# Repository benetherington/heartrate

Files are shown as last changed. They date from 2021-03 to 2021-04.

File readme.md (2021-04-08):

# benetherington/heartrate
A quick Arduino sketch using a Polar heartrate receiver to display individual
heartbeats, averaged heartrate, and a heartrate histogram.

## Dependencies
contrem/arduino-timer

## Hardware

* [Adafruit FeatherWing OLED - 128x64 OLED Add-on For Feather - STEMMA QT / Qwiic](https://www.adafruit.com/product/4650)

* [Heart Rate Educational Starter Pack with Polar Wireless Sensors](https://www.adafruit.com/product/1077)

* [Adafruit Feather M0 WiFi - ATSAMD21 + ATWINC1500](https://www.adafruit.com/product/3010) (Though you'd be hard
  pressed to find a Feather that wouldn't work!)

* [3.7v Li-Ion battery](https://www.adafruit.com/product/328) The enclosure is sized for Adafruit's biggest, linked
  here. It's 2500mAh.

## 3D Printed Enclosure
In the CAD folder, you'll find the original FreeCAD files, STLs of the four
parts, and two pre-sliced Gcode files for the Prusa Mk3. You'll also need velcro
cable straps, and an M3 flat-head screw. I used a 10mm long screw to take
advantage of the extra bite at the back of the hole which is printed as an
overhang in this orientation, but a shorter one would work as well. You don't
need much holding power here.

There are a few things to note about these files:
* The bottomcase has mounting posts spaced for the M0 WiFi. They're wider than
  the Feather standard calls for. If you use another, you'll have to modify the
  file. In the left sidebar, navigate to Enclosure > bottomcase > posts002 >
  posts001, and change constraint 4.
* If you don't want to use a screw for the battery door, consider adding tabs to
  the top of the door and the top of the door frame. The tabs holding the
  topcase and bottomcase together are a good example of how this might look.
* This design does not feature easy access to the USB port. I figured protection
  against sweat droplets was a priority. Instead, I spec'd Adafruit's biggest
  JST battery and added sleep capabilities to the Arduino code.

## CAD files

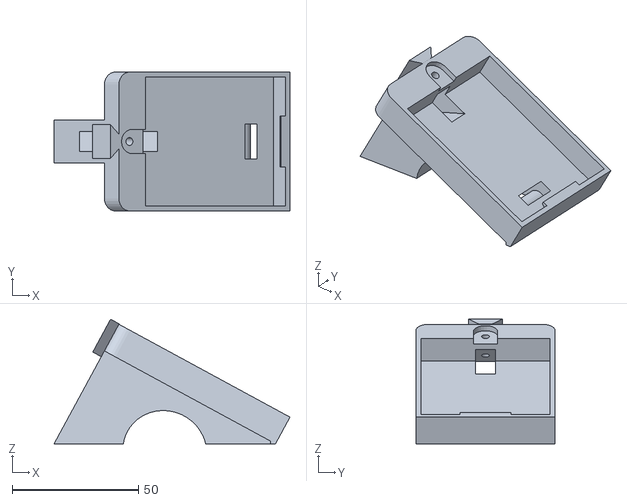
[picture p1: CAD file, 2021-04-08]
CAD/battery_and_mount.stl
93.3 x 55.0 x 49.3

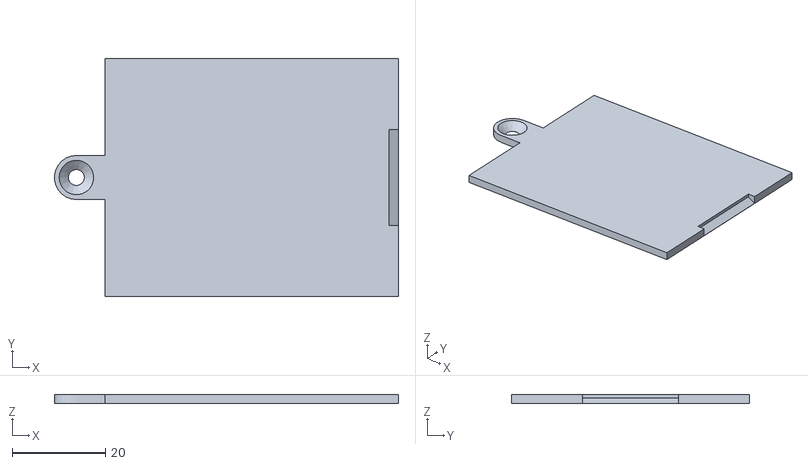
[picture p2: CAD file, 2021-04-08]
CAD/battery_door.stl
73.6 x 50.8 x 2.00

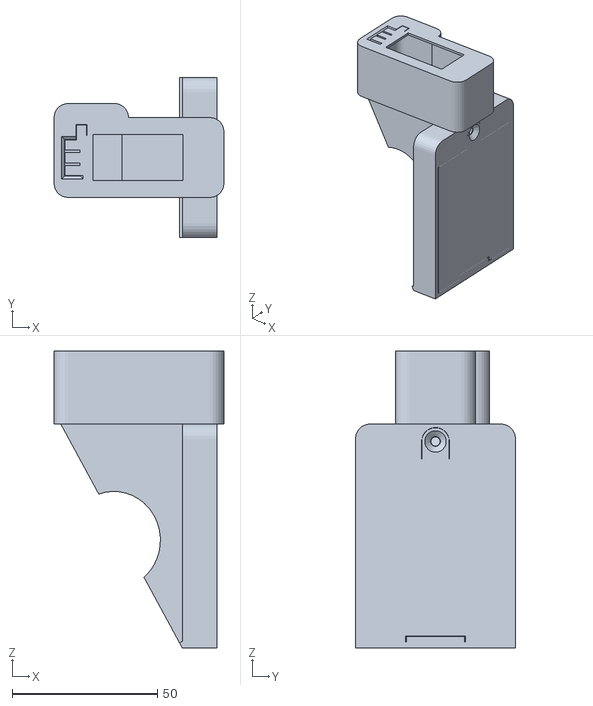
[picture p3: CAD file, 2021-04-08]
CAD/enclosure.stl
58.4 x 55.0 x 102.1

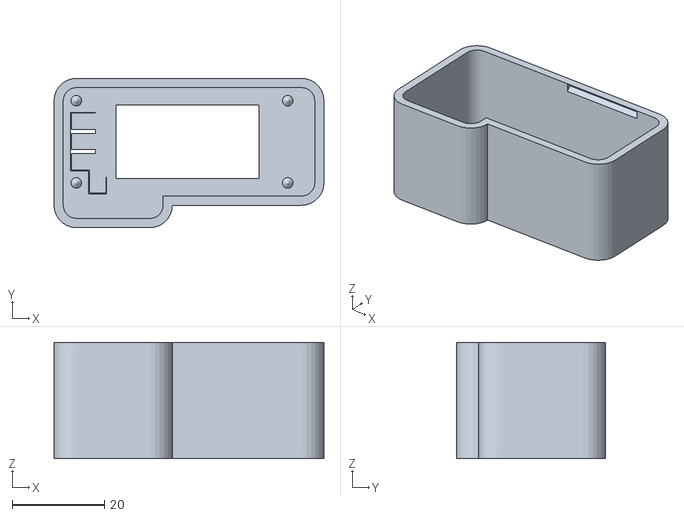
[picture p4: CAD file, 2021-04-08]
CAD/topcase.stl
58.4 x 32.3 x 25.1

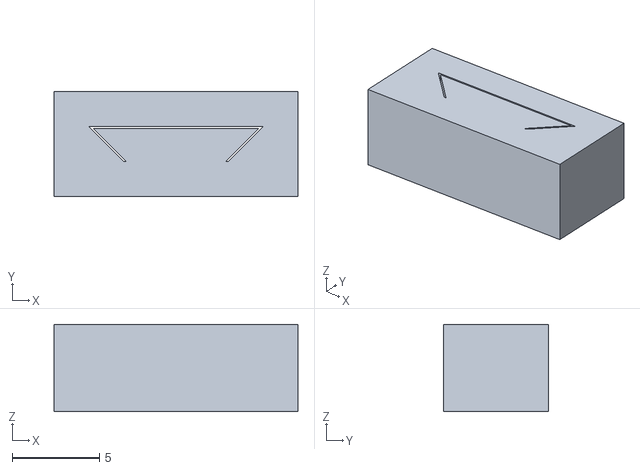
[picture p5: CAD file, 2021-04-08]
CAD/dovetail_test.stl
14.0 x 6.00 x 5.00

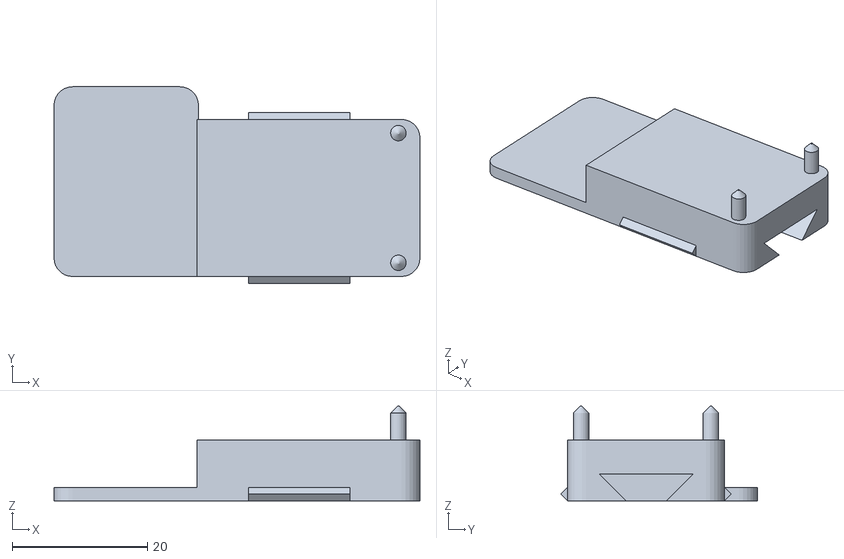
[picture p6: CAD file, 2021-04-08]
CAD/bottomcase.stl
54.2 x 29.1 x 14.0

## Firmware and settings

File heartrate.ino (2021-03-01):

#include <SPI.h>
#include <Wire.h>
#include <Adafruit_GFX.h>
#include <Adafruit_SH110X.h>
#include "arduino-timer.h"
#include "heartrate.h"

// IO
#define HR_RX     12
#define LED       13
#define BUTTON_A  9
#define BUTTON_B  6
#define BUTTON_C  5
Adafruit_SH110X display = Adafruit_SH110X(64, 128, &Wire);

// TIMERS
Timer<2>               timer;             // flash_heart, update_display.
Timer<2, millis, int>  led_timer;         // blink_led, led_off. Takes delay.
Timer<1, millis, bool> heart_pulse_timer; // display_heart_interior. Takes filled.

// CONFIGURABLE
#define FASTBLINK         100  // Blinkenlights for fun and debugging
#define SLOWBLINK         1000 //
#define HR_SAMPLE_RATE    2500 // Milliseconds to wait before displaying a new averaged HR
#define DISP_SPARK_HR_MIN 75   // Sparkline Y min in BPM
#define DISP_SPARK_HR_MAX 180  // Sparkline Y max in BPM

// GUI ARRANGEMENT
#define DISP_HEART_X 95 // Pulsing heart
#define DISP_HEART_Y 0  //
#define DISP_RATE_X  94 // Heartrate numerical display
#define DISP_RATE_Y  40 //
#define DISP_GRAPH_X 0  // Sparkline
#define DISP_GRAPH_Y 0  //
#define DISP_GRAPH_W 93 //
#define DISP_GRAPH_H 64 //


// GLOBALS
byte oldSample, sample;
bool newHeartbeat = false;
unsigned long heartrateSinceMillis = millis();
int heartbeatsSince = 0;



/* -------------- *\
|                  |
|  SETUP AND LOOP  |
|                  |
\* -------------- */

void setup() {
  // Change the true/false below to hotswap to button A as an alternate heartrate input.
  // This causes some odd behaviors due to the swapped polarity, but it's good enough for debugging.
  int debug_input;
  if (false) {
    debug_input = BUTTON_A;
  } else {
    debug_input = HR_RX;
  }

  // Set up pins, display, timers, callbacks
  Serial.begin(9600);
  Serial.println("INIT PINS");
  pinMode (HR_RX, INPUT);
  pinMode(LED, OUTPUT);
  pinMode(BUTTON_A, INPUT_PULLUP);
  pinMode(BUTTON_B, INPUT_PULLUP);
  pinMode(BUTTON_C, INPUT_PULLUP);

  Serial.println("INIT DISPLAY");
  display.begin(0x3C, true);
  display.clearDisplay(); // Love the Adafruit splash screen, but it's upside down for this setup!
  display.setRotation(3);
  init_display();
  display.display();

  Serial.println("INIT TIMERS");
  timer.every(100, flash_heart);
  timer.every(HR_SAMPLE_RATE, update_display);

  Serial.println("INIT INTERRUPTS");
  attachInterrupt(
    digitalPinToInterrupt(debug_input),
    []{newHeartbeat = true; heartbeatsSince += 1;},
    FALLING
  );

  Serial.println("Waiting for heart beat...");
  // led_timer.every(1000, blink_led, FASTBLINK);
  while (!digitalRead(debug_input)) {};
  Serial.println ("Heart beat detected!");
  
}
void loop() {
  // led_timer.tick();
  heart_pulse_timer.tick();
  timer.tick();
}

/* ------------- *\
|                 |
|  BLINKENLIGHTS  |
|                 |
\* ------------- */

bool blink_led(int duration) {
  Serial.println(duration);
  digitalWrite(13, HIGH);
  led_timer.in(duration, led_off, duration);
  return true;
}
bool led_off(int duration) {
  digitalWrite(13, LOW);
  return true;
}



/* ---------------------- *\
|                          |
|  HEARTRATE CALCULATIONS  |
|                          |
\* --------------------- */

template <uint8_t K, class uint_t = uint16_t>
class EMA {
  // Exponential moving average. Allows us to get a nice, smooth heartrate to display.
  // https://tttapa.github.io/Pages/Mathematics/Systems-and-Control-Theory/Digital-filters/Exponential%20Moving%20Average/C++Implementation.html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
  public:
    /// Update the filter with the given input and return the filtered output.
    uint_t operator()(uint_t input) {
        state += input;
        uint_t output = (state + half) >> K;
        state -= output;
        return output;
    }

    static_assert(
        uint_t(0) < uint_t(-1),  // Check that `uint_t` is an unsigned type
        "The `uint_t` type should be an unsigned integer, otherwise, "
        "the division using bit shifts is invalid.");

    /// Fixed point representation of one half, used for rounding.
    constexpr static uint_t half = 1 << (K - 1);

  private:
    uint_t state = 0;
};
int averaged_heartrate() {
  static EMA<2> filter;
  // calculate instant heartrate
  float deltaMillis = millis() - heartrateSinceMillis;
  float instantHeartrate = heartbeatsSince / deltaMillis // beats per milli
                           * 1000                        // beats per second
                           * 60;                         // beats per minute
  // reset counters
  heartrateSinceMillis = millis(); heartbeatsSince = 0;
  // return average
  return filter(instantHeartrate);
}


/* -------- *\
|            |
|  GRAPHICS  |
|            |
\* -------- */

void init_display() {
  // heart outline
  display.drawBitmap(DISP_HEART_X, DISP_HEART_Y, heartNoInterior, 33, 32, SH110X_WHITE);
  // graph area
  display.drawRoundRect(
    DISP_GRAPH_X,
    DISP_GRAPH_Y,
    DISP_GRAPH_W,
    DISP_GRAPH_H,
    5,
    SH110X_WHITE
  );
  display.setTextColor(SH110X_WHITE, SH110X_BLACK);
  display.setTextSize(2);
  display.setTextWrap(false);
}

bool update_display(void*) {
  int average_hr = averaged_heartrate();
  update_text(average_hr);
  update_graph(average_hr);
  return true;
}

void update_text(int heartrate) {
  display.setCursor(DISP_RATE_X, DISP_RATE_Y);
  display.print(heartrate); display.print("  ");
}

#define DISP_SPARK_MIN    DISP_GRAPH_X+2
#define DISP_SPARK_MAX    DISP_SPARK_MIN+DISP_GRAPH_W-4
int graph_cursor_position = DISP_SPARK_MIN;
void update_graph(int heartrate) {
  // Calculate scaled Y position
  int bounded_hr = min(max(heartrate, DISP_SPARK_HR_MIN), DISP_SPARK_HR_MAX);
  float excess_hr = bounded_hr-DISP_SPARK_HR_MIN;
  static float display_ratio =
    (float)(DISP_SPARK_HR_MAX-DISP_SPARK_HR_MIN)
    /
    (float)(DISP_GRAPH_Y+DISP_GRAPH_H-4);
  static int bottom_of_graph = (DISP_GRAPH_Y+DISP_GRAPH_H-4);
  float heartrate_pixel_y = bottom_of_graph-excess_hr*display_ratio;

  // Set cursor
  graph_cursor_position += 1;
  if (graph_cursor_position > DISP_SPARK_MAX) {
    graph_cursor_position = DISP_SPARK_MIN;
  }
  // Clear columns
  display.drawFastVLine(
    graph_cursor_position, DISP_GRAPH_Y+3,
    DISP_GRAPH_H-6, SH110X_BLACK
  );
  if (graph_cursor_position > DISP_SPARK_MAX) {
    display.drawFastVLine(
      graph_cursor_position+1, DISP_GRAPH_Y+3,
      DISP_GRAPH_H-6, SH110X_BLACK
    );
  }
  // Draw pixel
  display.drawPixel(
    graph_cursor_position,
    heartrate_pixel_y,
    SH110X_WHITE
  );
}

bool flash_heart(void*) {
  if (newHeartbeat) {
    display_heart_interior(true);
    heart_pulse_timer.in(100, display_heart_interior, false);
    newHeartbeat = false;
  }
  return true;
}

bool display_heart_interior(bool filled) {
  // display.clearDisplay();
  if (filled) {
    display.drawBitmap(DISP_HEART_X, DISP_HEART_Y, heartInterior, 33, 32, SH110X_WHITE);
  } else {
    display.drawBitmap(DISP_HEART_X, DISP_HEART_Y, heartInterior, 33, 32, SH110X_BLACK);
  }
  display.display();
  return true;
}
